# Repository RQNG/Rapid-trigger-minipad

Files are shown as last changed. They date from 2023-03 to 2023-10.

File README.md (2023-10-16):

# Rapid-trigger-minipad
Rapid trigger是Wooting键盘的特色功能，是指没有固定键程，靠上下移动判定触发的功能，能解决切指卡手的大难题，传言能破解osu!这款游戏。

我本来想尝试一下wooting，但其价格昂贵，没有渠道，二手抢钱等等问题让我很不爽，于是决定自己做，我想这也是许多玩家想做的，所以我将它分享出来，现在，它属于每一名玩家了。

本项目提供三种主控方案，其中以STM32为主，出于性能和性价比考虑，CH552和RP2040版本将不再更新，但仍然保留代码给有需要的人。

按键为独立模块并且全部使用杜邦线连接，按键间距可调，STM32版本最多支持10个模拟输入按键，这应该能满足大部分玩家在按键数量和个性化上的需求了。

这并不是很厉害的技术，但确实还算有趣，感兴趣的话欢迎尝试制作。我希望这个项目越多人关注越好，最好在玩家群体里流行开来，我认为这种功能被说是走捷径的根源就是不够普及，所以都来用吧。

参考或使用此项目请遵守附带的开源协议，如愿意分享，欢迎投稿至第三方文件夹。



# 项目特点
* 制作简单，无需任何专业操作（如焊接等）和专业知识就能制作。
* 无法垄断，所有材料在国内都有渠道购买并且供货充足。
* 本地控制，增加控制器，除按键总键程外，所有设置都可以在本地完成。
* 丝滑菜单，控制器使用模仿稚晖君MonoUI的多级菜单，动画被优化到非常丝滑，可以当解压玩具（真的）。
* 按键数多，最多能添加10个模拟按键，多于市面上其它方案，并且每个按键都可以不一样。
* 三种模式，支持不同极性按键，不同极性传感器的所有组合，组合对应两个模式，还有禁用模式。
* 键距可调，每个按键为独立制作并且可以在外壳内自由摆放，提供多种宽度的填充模块。
* 成本较低，使用stm32作为主控，价格比arduino更低，按键数量可以自行选择以降低成本。
* 性能更好，经测试，ADC精度比频率等因素更影响表现，而stm32有精度更高的ADC，因此是最优选择。

# 控制器
主菜单：

屏幕截图 2023-05-29 011856

编辑页：

屏幕截图 2023-05-29 012131

弹窗：

屏幕截图 2023-05-29 012300

电压测量页：

屏幕截图 2023-05-29 012449

演示视频：https://www.bilibili.com/video/BV17T41187xi/

控制器使用0.96寸OLED显示，EC11旋钮控制，使用了我的另一个项目：WouoUI，关于UI的描述请查看该项目。

控制器支持调整的参数：
* 触发值
* 释放值
* 上死区
* 下死区
* 键值
* 模式（压缩包内的代码不支持该项）
* 初始化时放大抖动的倍数

注意：
* 外壳模型尚未支持安装屏幕和旋钮，请自行修改外壳，否则请使用压缩包内的代码。
* 安装轴体下的磁铁时，请使用压缩包内的工具代码，检查磁铁方向是否安装正确，要求按下增大，释放减小。
* 控制器是给以后可能使用的成品轴体设计的，轴体极性不确定，手制轴体的话，可以确保表现的唯一，无需另一种模式。
* 压缩包内的代码，Rapid trigger功能部分，与更高版本没有本质区别，无需介意版本号较低。

# 内部结构
四按键版本：

Notes_230225_033130_2

十按键版本：

Notes_230225_033130_2 (1)

# 制作教程
1. 轴体改造篇：https://www.bilibili.com/read/cv21948435
2. 软件设置篇：https://www.bilibili.com/read/cv21969155
3. 硬件组装篇：https://www.bilibili.com/read/cv21985212

# 参考项目
1. hall-2k-keypad-handmade：https://github.com/chent7/hall-2k-keypad-handmade（主要）
2. 如何DIY一款属于自己的HID键盘：https://mp.weixin.qq.com/s/o-8_3SQS2AGT_WTyTLYQnA
3. 【三键侧透光小键盘】CH552G：https://oshwhub.com/phantomr/styudy-xiao-jian-pan-ch552g

# 推荐项目
下列项目都有Rapid trigger功能，它们各有优势，对我的项目有建议的，在给出建议之外，也可以尝试在这些项目中寻找解决方案。

* hall-2k-keypad-handmade: https://github.com/chent7/hall-2k-keypad-handmade
* cap4k：https://github.com/MaticsL/cap4k
* minipad-firmware-old: https://github.com/minipadKB/minipad-firmware-old
* minipad-firmware: https://github.com/minipadKB/minipad-firmware
* fluxpad: https://github.com/sssata/fluxpad
* the-poor-mans-keypad-and-future-wooting: https://www.reddit.com/r/osugame/comments/zpcvkw/the_poor_mans_keypad_and_future_wooting/
* making-a-diy-wooting-keypad: https://www.reddit.com/r/osugame/comments/117v6xd/making_a_diy_wooting_keypad/
* DIY under 20$ WOOTING like Keypad for Osu! (analog switches): https://www.youtube.com/watch?v=4rrDy9KakRI&t=10s&ab_channel=prAlex
* BexPad: https://github.com/Bexin3/BexPad

# 改进空间
目前我的方案在通用性和表现上都已经很不错了，动手能力不强的普通玩家完全可以放心尝试，不会令你们失望的。
对于不惜代价追求极致的人来说，我的方案可能显得太过廉价，因此在这里提出一些改进空间，欢迎尝试，如果愿意分享的话，请合并在第三方设计项目中供他人参考。

* 使用stm32作为主控，不是因为廉价，而是因为它拥有最高的ADC分辨率，这个最影响体验。
* 使用stm32标准库或者hal库实现通信功能，因为有成熟的方案可用，但因为IDE劝退新手而弃用。
* 使用AH491线性霍尔传感器，这种灵敏度很高为15mv/Gs，但相对的会放大抖动，因为不好调试而弃用。
* 使用pcb，能降低干扰并且有助于批量化生产，但因为无法实现可调键距和需要焊接而弃用。
* 使用成品磁轴，轴芯有个小磁铁跟着上下移动的那种，因为有垄断风险而弃用，目前已知的有三种：
  1. wooting的lekker轴，这个要海淘。
  2. 佳达隆的ks-20，这个买不到。
  3. 东莞市益谦电子有限公司，1688搜索“磁轴”能找到，应该能买到。

# 建议收集
可以直接在GitHub上提建议，也可以在B站专门的动态下提。

* 初版方案建议收集动态：https://t.bilibili.com/757193959862697993

# 赛博乞讨（划掉
开发不易，如果有帮到你，请我喝杯咖啡可好


# 更新
## 软件

### v 3.2
* 优化动画函数，动画结束后不会再进行无意义的浮点数计算。

### v 3.1
* 修复EC11旋钮使界面卡死的问题，感谢 GitHub 安红豆 提供的线索。

### v 3.0
* UI 流畅度优化，实现了优雅的平滑动画，动画算法被优化到只有两行。
* UI 架构优化，基本重构了 v2.x，实现了独立弹窗，白天和黑暗模式，单选和多选框，开关等。
* 删除主界面列表菜单风格，增加主界面图标动画可选项。
* 删除关于本机页配置查看功能，增加参数修改页面，参数直接显示在每行末尾功能。
* 选择框跳转动画改为宽度和竖直方向位置都从当前位置到上一级选中位置平滑过渡。
* 增加动画速度可调区间。10 ~ 100。
* 修复循环模式选择框在跳转动画未结束前，选择项后退时，列表与屏幕错位的问题。
* 修复选择框在选择滚动过快时，滚出屏幕外的问题。
* 增加独立弹窗动画，背景虚化开关功能。
* 重新设计电压测试页，增加波形显示功能，现在可以同时观察数值和波形。

### v 2.1
* 重构代码，只保存路径和选择框所在位置，分页面类型定义变量。
* 增加图标和列表两种主界面风格。
* 支持本地查看所有配置，在关于本机页面。
* 支持128×64，128×32两种主流OLED屏幕分辨率，只需要替换驱动即可。
* 增加列表展开动画效果。
* 增加选择框展开和跳转动画效果。
* 增强动画速度的可调精度。
* 增加循环模式。
* 增加旋钮方向反转选项。

### v 2.0
* 增加模仿MonoUI的丝滑菜单。
* 支持不同极性的轴和不同极性的传感器，使用对应模式即可。
* 支持在本地设置所有参数。
* 支持断电保存功能。
* 支持引脚测试，可以在本地查看引脚电压变化曲线。

### v 1.3
* 初始化改为并行扫描，按键数增加不会明显延长初始化时间。
* 增加初始化指示灯，在板子上的蓝灯未熄灭前，不要按下按键。

### v 1.2 
* 解决了插入后微小干扰下误触发的bug。
* 增加了上下死区。
* 增加除字母外其它按键的支持。

### v 1.1 
* 解决了插入后不断输入的bug。
* 优化了初始化方式。

### v 1.0 
* 简单移植hall-2k-keypad-handmade。

## 硬件：

### v 1.2
* 增加OLED显示屏。
* 增加EC11旋钮。

### v 1.1 
* 增加十按键版本外壳模型。
* 增加几种填充模块模型。

### v 1.0 
* 四按键版本外壳模型。
* 独立按键所需模型。
* 材料清单。

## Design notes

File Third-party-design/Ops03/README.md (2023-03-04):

# 未经验证，谨慎使用

# Ops03 by OctopusZ
Ops03 是一个基于ch552t，使用了三个磁轴的键盘项目

# without verification，Use with caution

# Ops03 by OctopusZ
Ops03 is a keyboard project based on ch552t and using three magnetic swtich.

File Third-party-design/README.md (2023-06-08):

# 第三方项目
基于Rapid-trigger-minipad展开的第三方项目

# 目录
* Ops03：基于ch552t，使用了三个磁轴的键盘项目，作者：OctopusZ
* wheatPad：作者：wheatEars

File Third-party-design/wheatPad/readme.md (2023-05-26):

# 注意

方案未经验证，谨慎使用

新增两个微动，修改ui程序可以用来按esc和重开~

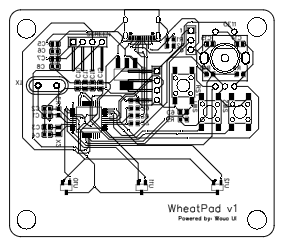
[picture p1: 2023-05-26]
Third-party-design/wheatPad/PCB.png

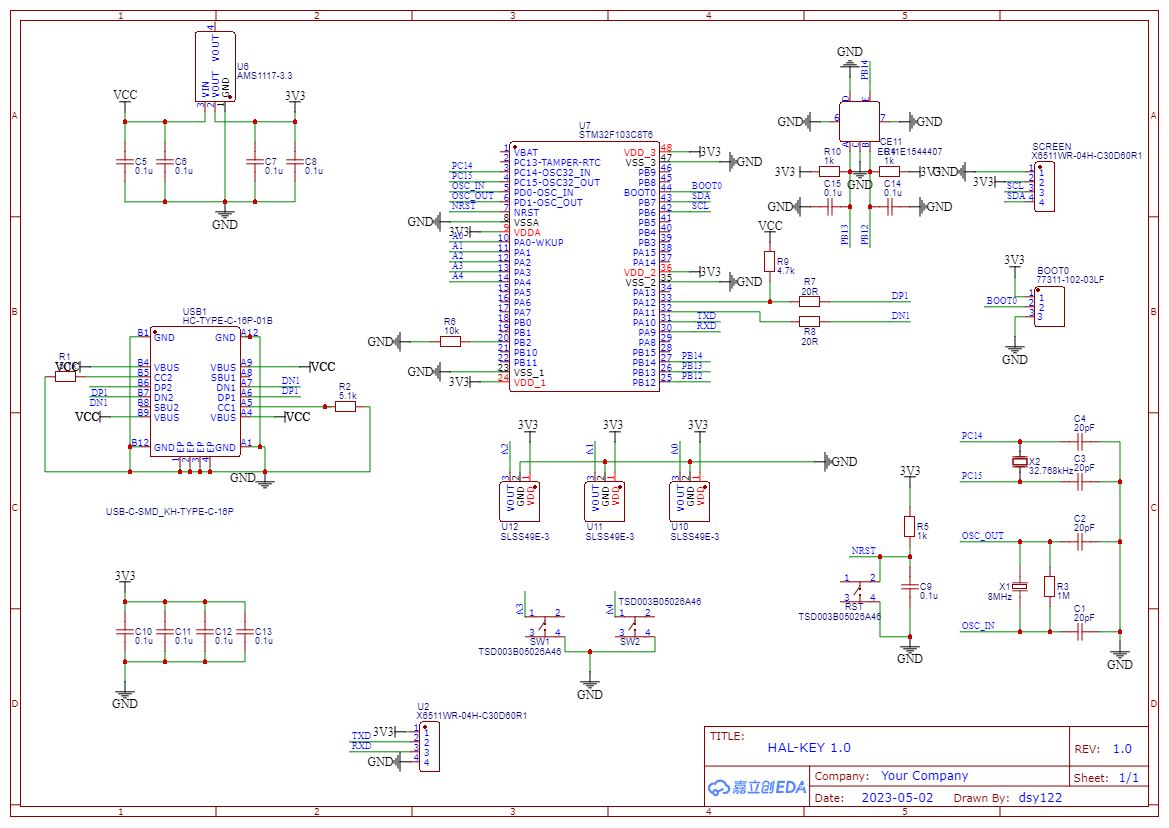
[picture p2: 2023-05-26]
Third-party-design/wheatPad/原理图.png

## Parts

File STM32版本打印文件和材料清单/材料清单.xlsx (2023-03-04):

工具 | 数量 | 价格 | 店铺 | 备注 | 可用的线性霍尔传感器
锉刀，镀镍3mm×5件套 | 1件 | 9.5 | greener绿林旗舰店 |  | SS49E | 1.8 - 2.0 mv/G
刻刀 | 1把 | ？ | 楼下小卖部 |  | MH49E | 1.8 - 2.0 mv/G
502胶水（晨光，粘稠状） | 1管 | ？ | 楼下小卖部 |  | AH602 | 2.5 mv/G
拆轴器 | 1个 | ？ | 未知 | 我是用牙线尾端撬开的 | AH603 | 3.25 mv/G
斜嘴钳 | 1把 | ？ | 本来就有 |  | AH605 | 5 mv/G
尖嘴钳 | 1把 | ？ | 本来就有 |  | CH603 | 3.3 mv/G
尺子 | 1把 | ？ | 本来就有 |  | CH604 | 2.5 mv/G
 |  |  |  |  | CH605 | 5 mv/G
 |  |  |  |  | AH491 | 15 mv/G
 |  |  |  |  | AH492 | 7.5 mv/G
 |  |  |  |  | AH493 | 3.7 mv/G
材料 | 数量 | 价格 | 店铺 | 备注 | AH494 | 2 mv/G
杜邦线，10cm，公对公 | 1排 | 3.44 | risym旗舰店
杜邦线，10cm，公对母 | 1排 | 3.56 | risym旗舰店
杜邦线，21cm，母对母 | 1排 | 2.38 | risym旗舰店 | 十按键版本不知道怎么买，自己估计一下
圆柱形磁铁，直径2mm，厚3mm | 50个 | 6.5 | 博讯微数码专营店
TTC新版金粉轴V2 | 4个 | 12.8 | 深圳市金盛达电子 | 建议多买几个练手
STM32F103C8T6单片机，排针向下焊接 | 1个 | 17.1 | 无名科技Nologo
线性霍尔传感器 | 4个 | 10 | 深圳信芯电子商行 | 多种型号可以用，详情看右边的列表，捡有货的最灵敏的买即可，体感差别不大，选直插型号的
H62黄铜管，外径2mm，内径1.6mm，0.5m | 1根 | 10 | 上海金属材料经营部
面包板，长8.5cm，宽5.5cm | 1个 | 2.8 | 深圳市优信电子科技有限公司
USB转TTL模块 | 1个 | 4.5 | 深圳市优信电子科技有限公司
3D打印 | 1次 | 90 | 卓越三维产品设计打印服务 | 不要用三维猴打印，精度不够

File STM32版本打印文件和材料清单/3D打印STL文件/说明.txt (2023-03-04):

文件夹名称表示的数量为该外壳最多能容纳的按键数量，不代表真的要做那么多按键。

如果不需要那么多按键，请选择填充模块进行填充，填充模块可以用于调节按键间距。

请先确定好所需按键数和摆放方式，选择合适的外壳模型和填充模块，确定好数量。

注意，十按键版触盘外壳未经过实际测试，如果有任何问题请在建议动态中留言，

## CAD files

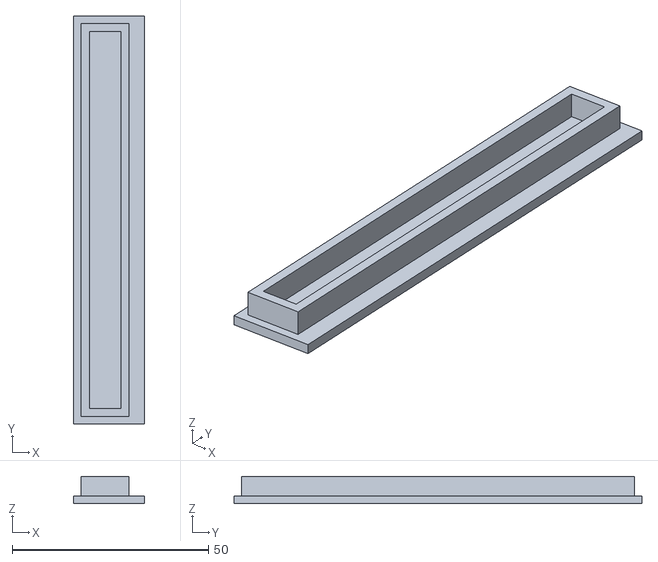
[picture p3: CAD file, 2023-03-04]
STM32版本打印文件和材料清单/3D打印STL文件/十按键版触盘外壳打印件/4. 触盘外壳D，2件.stl
18.0 x 104.0 x 7.00

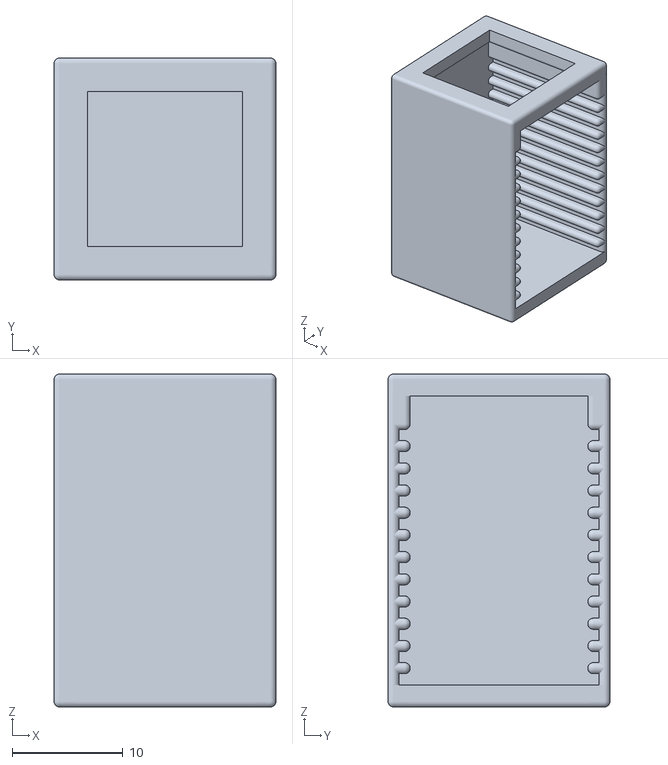
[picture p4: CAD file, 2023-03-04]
STM32版本打印文件和材料清单/3D打印STL文件/单个按键打印件/4. 按键外壳，1件.stl
20.0 x 20.0 x 30.0

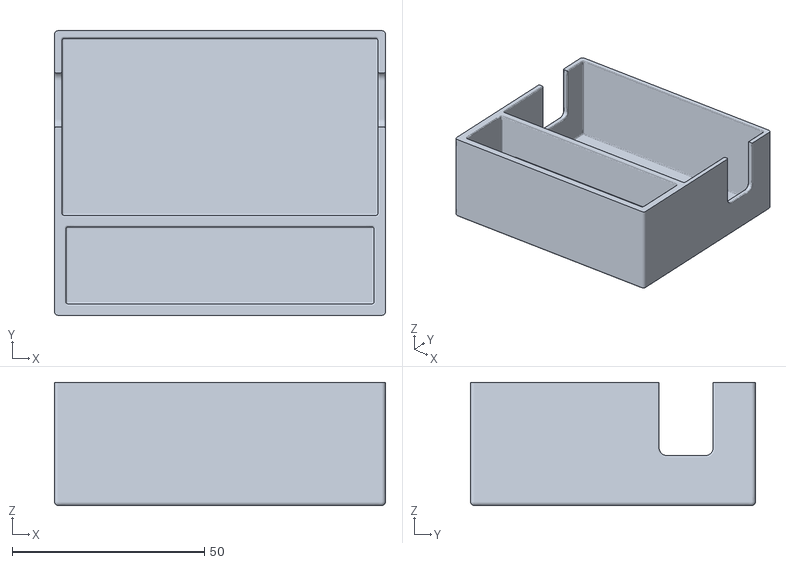
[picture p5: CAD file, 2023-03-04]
STM32版本打印文件和材料清单/3D打印STL文件/四按键版触盘外壳打印件/1. 触盘外壳A，1件.stl
86.0 x 74.0 x 32.0

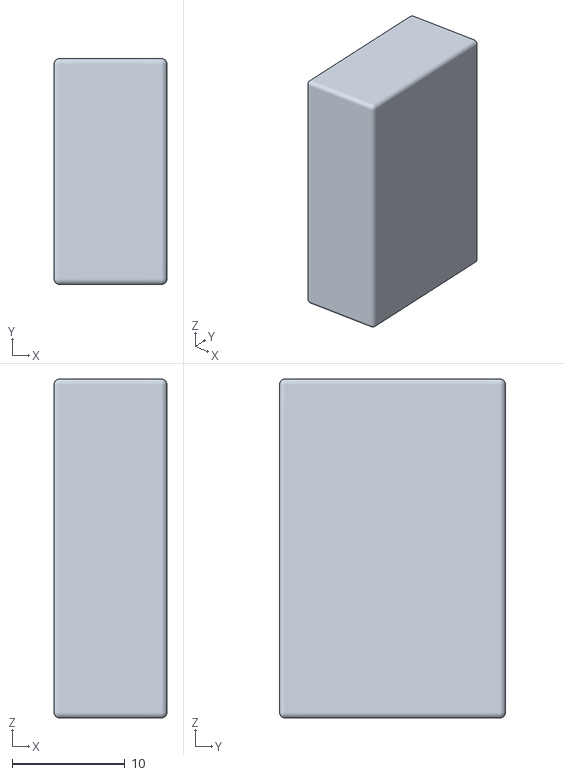
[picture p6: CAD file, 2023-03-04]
STM32版本打印文件和材料清单/3D打印STL文件/填充模块打印件/一个按键长，半个按键宽的填充块.stl
10.0 x 20.0 x 30.0

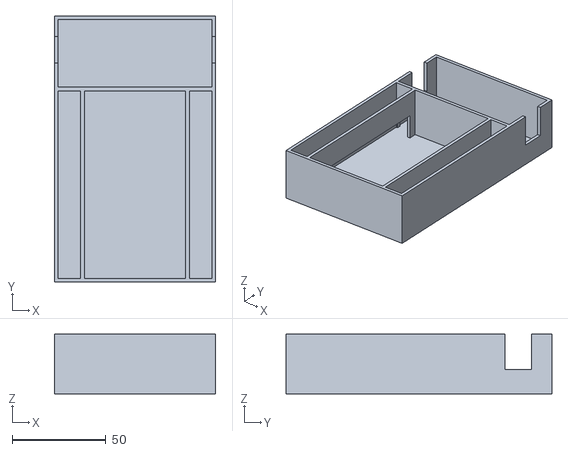
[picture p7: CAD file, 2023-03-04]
STM32版本打印文件和材料清单/3D打印STL文件/十按键版触盘外壳打印件/1. 触盘外壳A，1件.stl
86.0 x 142.0 x 32.0

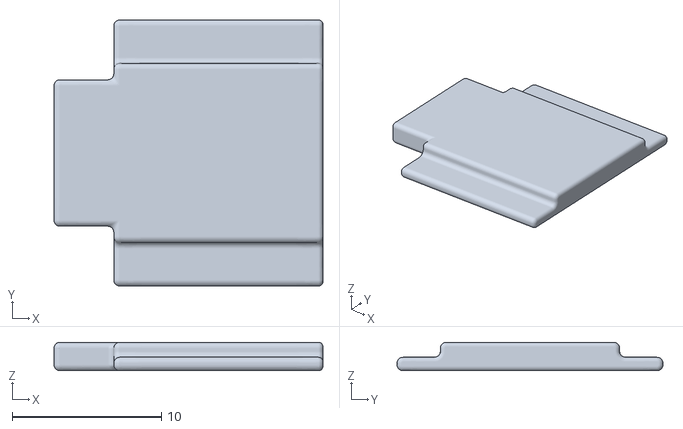
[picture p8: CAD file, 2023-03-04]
STM32版本打印文件和材料清单/3D打印STL文件/单个按键打印件/3 .探头固定器B，1件.stl
18.0 x 17.8 x 1.90

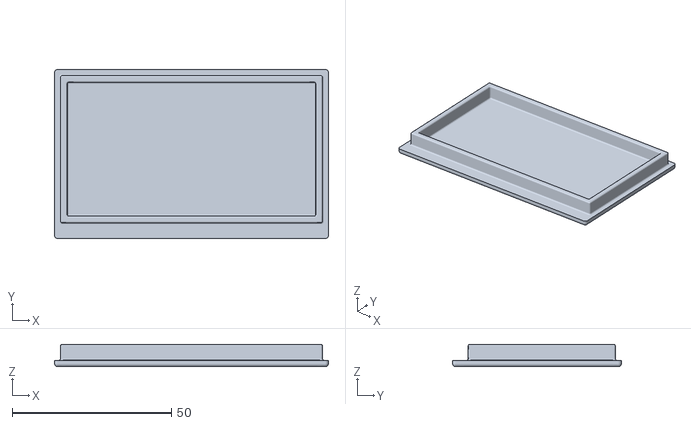
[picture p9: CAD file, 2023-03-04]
STM32版本打印文件和材料清单/3D打印STL文件/四按键版触盘外壳打印件/2. 触盘外壳B，1件.stl
86.0 x 53.0 x 7.00

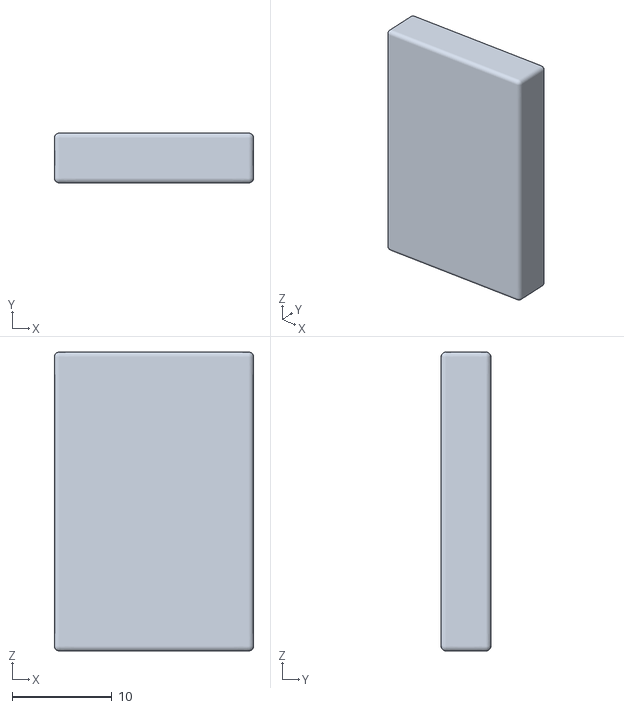
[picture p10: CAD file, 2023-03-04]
STM32版本打印文件和材料清单/3D打印STL文件/填充模块打印件/一个按键长，四分之一个按键宽的填充块.stl
20.0 x 5.00 x 30.0

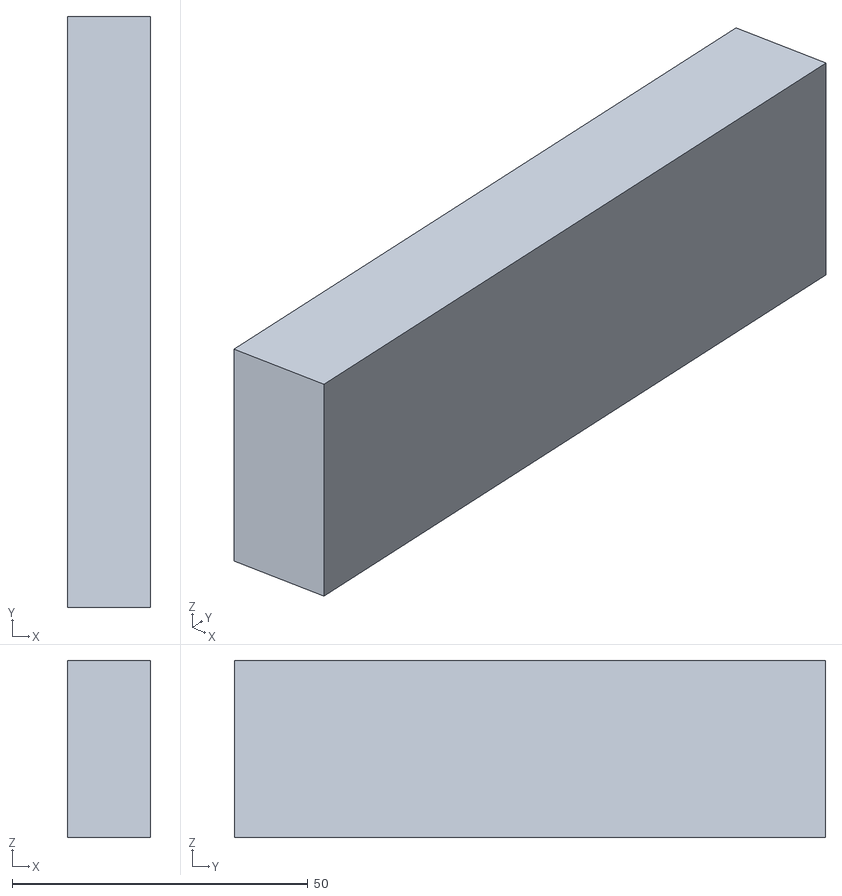
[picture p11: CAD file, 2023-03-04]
STM32版本打印文件和材料清单/3D打印STL文件/十按键版触盘外壳打印件/3. 触盘外壳C，1件.stl
14.0 x 100.0 x 30.0

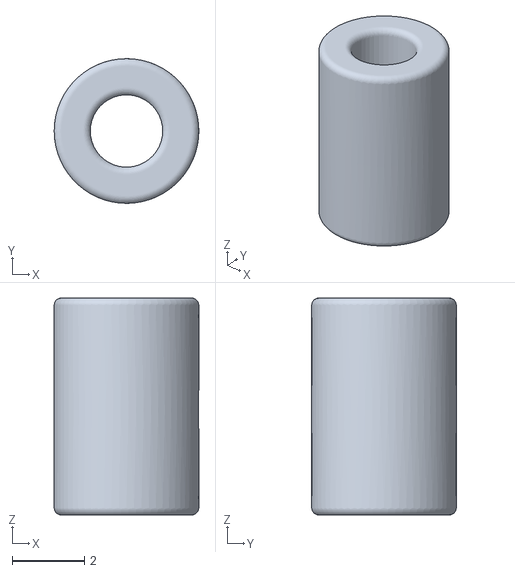
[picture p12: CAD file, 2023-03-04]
STM32版本打印文件和材料清单/3D打印STL文件/单个按键打印件/1. 磁铁固定器，1件.stl
4.00 x 4.00 x 6.00

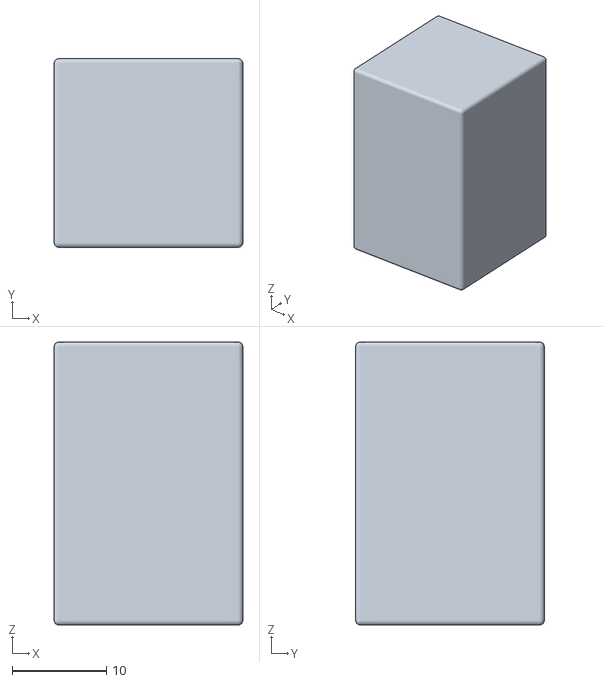
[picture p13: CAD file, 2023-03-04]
STM32版本打印文件和材料清单/3D打印STL文件/填充模块打印件/一个按键长，一个按键宽的填充块.stl
20.0 x 20.0 x 30.0

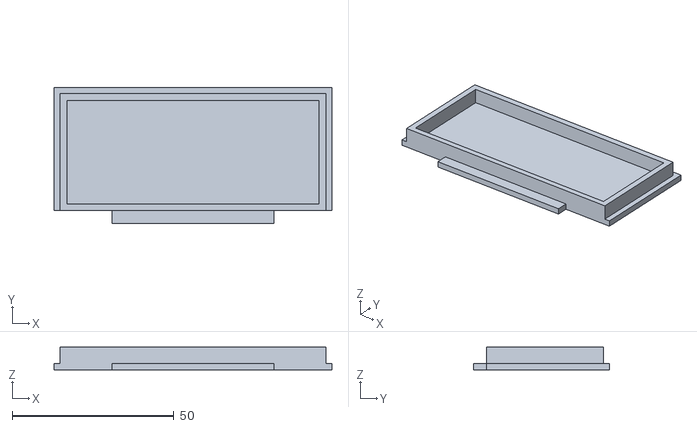
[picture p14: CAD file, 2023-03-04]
STM32版本打印文件和材料清单/3D打印STL文件/十按键版触盘外壳打印件/2. 触盘外壳B，1件.stl
86.0 x 42.0 x 7.00

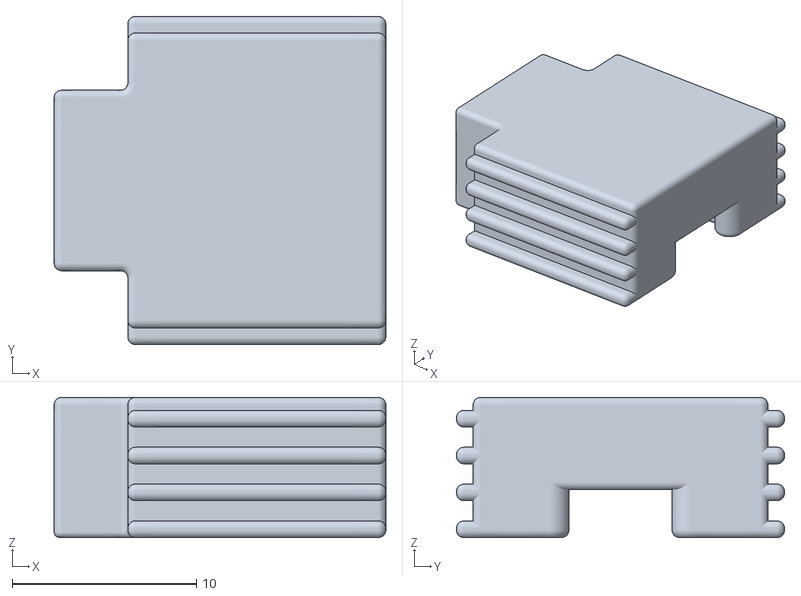
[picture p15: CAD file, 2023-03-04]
STM32版本打印文件和材料清单/3D打印STL文件/单个按键打印件/2. 探头固定器A，1件.stl
18.0 x 17.8 x 7.60

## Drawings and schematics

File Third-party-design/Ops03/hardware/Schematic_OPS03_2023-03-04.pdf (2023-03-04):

## USB接口

GND B1A12 VBUS A9B4 CC1 A5 DP1 A6 DN1 A7 SBU1 A8 CC2 B5 DP2 B6 DN2 B7 SBU2 B8 VBUS A9B4 GND B1A12 SHELL 0

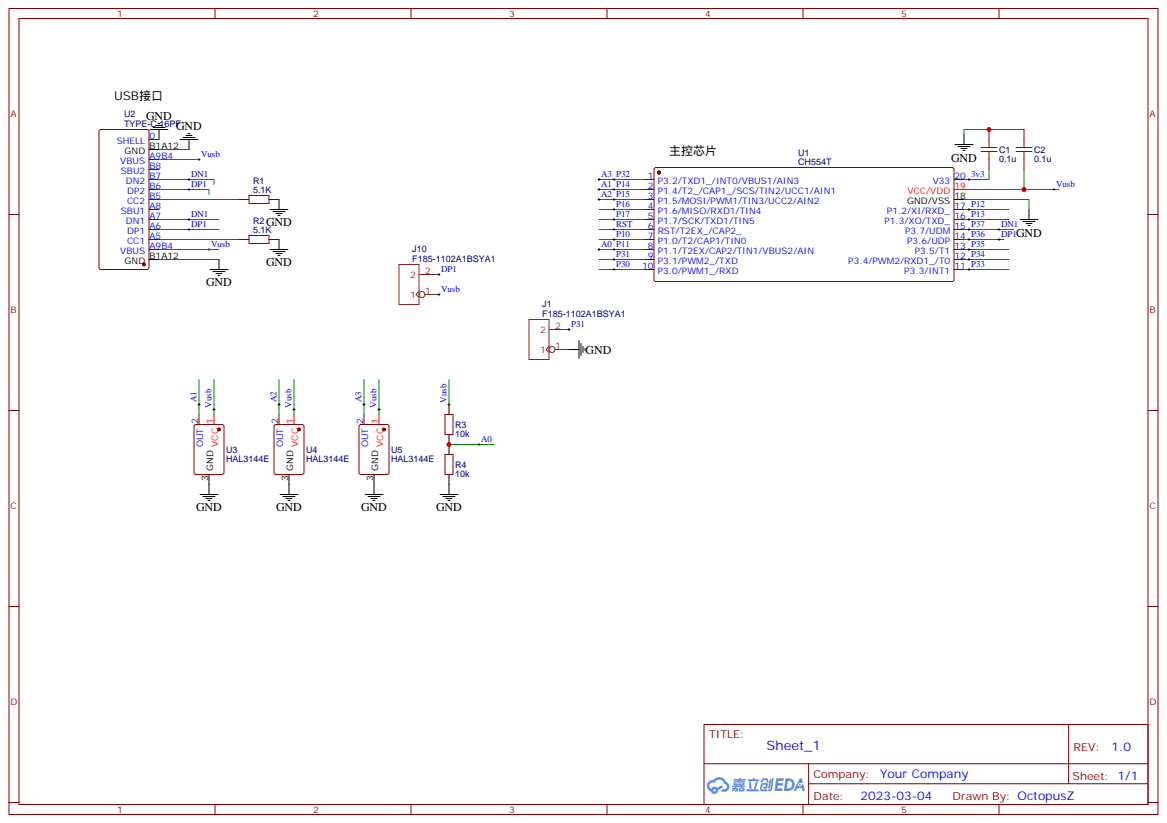
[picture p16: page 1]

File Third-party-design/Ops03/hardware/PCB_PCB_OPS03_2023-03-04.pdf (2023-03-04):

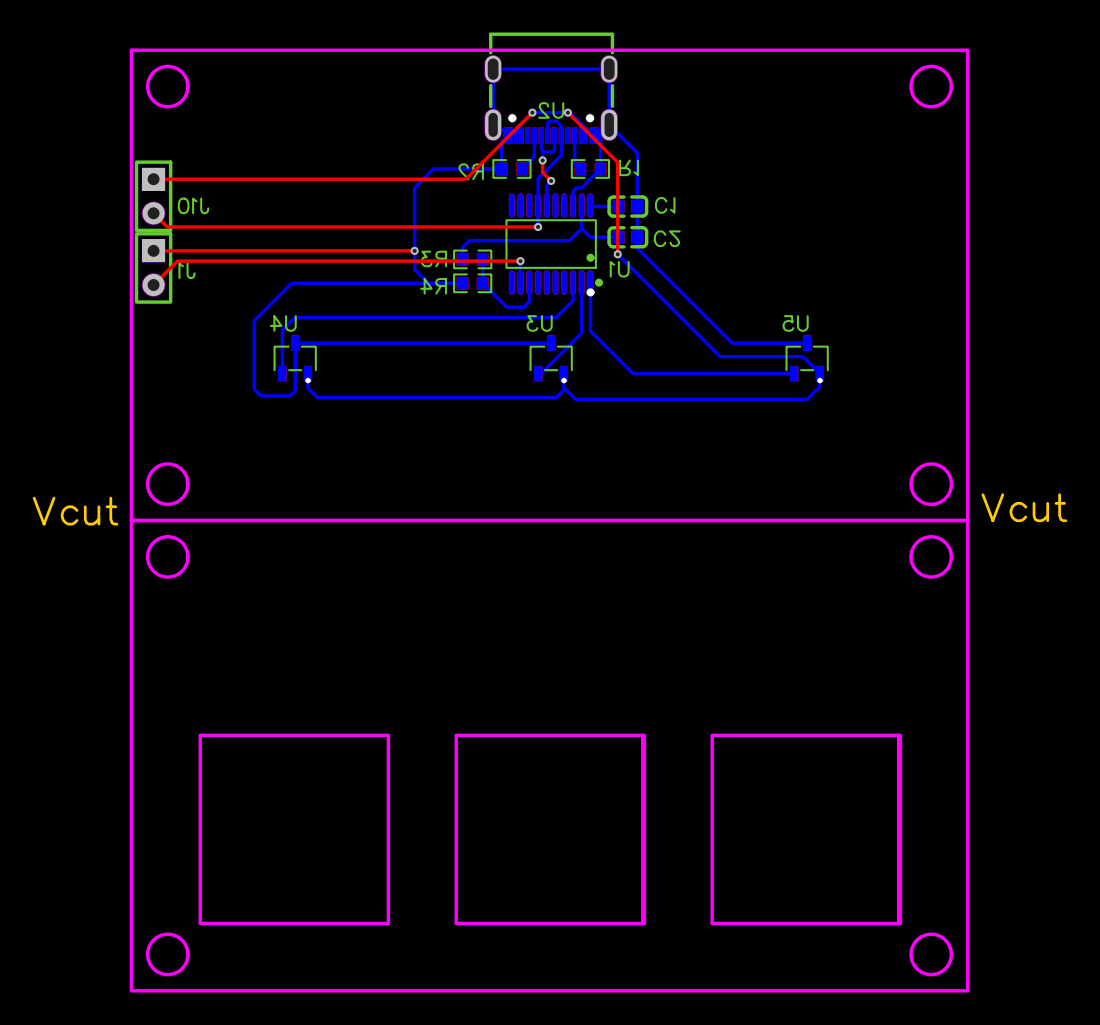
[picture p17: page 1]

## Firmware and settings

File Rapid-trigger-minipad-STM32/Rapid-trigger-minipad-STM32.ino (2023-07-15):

/*
  此程序用于实现 wooting 键盘中的 Rapid trigger 功能。
  
  主功能移植并优化自 Github 上的一个开源项目，添加了按键的独立参数和两端的死区，优化了初始化方式，增加控制器，模仿稚晖君 MonoUI 的超丝滑菜单。

  v3.2 更新内容：

    * 优化动画函数，动画结束后不会再进行无意义的浮点数计算
    
  v3 功能：

    * 此程序可视为 WouoUI v2.0 例程，WouoUI 是从此程序 v2.x 版本衍生出的 UI 架构。
    * UI 流畅度优化，实现了优雅的平滑动画，动画算法被优化到只有两行。
    * UI 架构优化，基本重构了 v2.x，实现了独立弹窗，白天和黑暗模式，单选和多选框，开关等功能。
    * 删除主界面列表菜单风格，增加主界面图标动画可选项，回到主界面时，图标可以从正上方当前位置向两边发牌，或者从左上方从头开始发牌。
    * 删除关于本机页配置查看功能，增加参数修改页面，参数直接显示在每行末尾功能。
    * 选择框跳转动画改为宽度和竖直方向位置都从当前位置到上一级选中位置平滑过渡。
    * 增加动画速度可调区间。10 ~ 100。
    * 修复循环模式选择框在跳转动画未结束前，选择项后退时，列表与屏幕错位的问题。
    * 修复选择框在选择滚动过快时，滚出屏幕外的问题（虽然我觉得这是个有趣的特性，只要往回滚动就好不影响正常使用）。
    * 增加独立弹窗动画，背景虚化开关功能（开启虚化会有轻微卡顿感，但或许有些人喜欢，因此保留可选项）。
    * 重新设计电压测试页，增加波形显示功能，现在可以同时观察数值和波形。
  
  测试用开发板为STM32 F103C8T6，以下是使用说明：

    硬件：

    * EC11：A -> PB13 ; B -> PB12 ; S -> PB14 ; 电源3.3v
    * OLED：四线，0.96 SSD1306 128*64，SDA -> PB7 ; SCL -> PB6 ; 电源3.3v
    * 板子上的跳线帽设置：BOOT0 -> 1 ; BOOT1 -> 0 
    * 串口模块与板子连线：GND -> GND ; 3V3 -> 3.3V ; RX -> PA9 ; TX -> PA10，其余引脚空着。
    * 串口与电脑连接，用数据线连接板子上的母口和电脑。
    * 点击IDE左上角向右箭头的按钮，等待编译和上传完成。
    * 上传完成后如要测试手感，无需断开串口模块，但需要拔插数据线，电脑才能识别到是USB设备。
    * 当BOOT在第一条所述设置时，上传完成后，第一次拔插数据线时电脑会认到USB设备，从第二次开始就认不到了。
    * 手感调试合适后修改跳线帽的设置为：BOOT0 -> 0 ; BOOT1 -> 0。设置后就能收起串口模块了。
  
    软件：
    
    * 文件 -> 首选项 -> 其他开发板管理器地址 -> 添加一行：http://dan.drown.org/stm32duino/package_STM32duino_index.json
    * 工具 -> 开发板 -> 开发板管理器 -> 搜索stm32F1，下载STM32F1xx开头的库
    * 工具 -> 开发板 -> stm32F1... -> Generic STM32F103C series
    * 工具 -> 端口：“COMX” -> COMX（X为设备对应端口号）
    * 工具 -> Upload method -> Serial
    * 进入目录C:\Users{username}\AppData\Local\Arduino15\packages\stm32duino\hardware\STM32F1{版本名称}\libraries\USBComposite下，打开usb_hid.c文件，搜索bInterval，将该值修改为0x01，即轮询间隔修改为1ms
    
    注意：

    * 上传程序前，先确认使用的轴的总键程是否为4mm，如果不是，需要修改 key 数组变量中代表 travel 一列的相关参数，单位0.1mm，即4mm的值为40。
    * 拔插USB后，正常情况下，屏幕会变黑，板子上的蓝灯会点亮一秒钟，点亮时不要动按键，这是在初始化。
    * 初始化后，每个按键都需要按下一次后才能正常使用，按下时要按到底。

  遇到困难的话参考以下资料：

    设置参考：
    
    * https://github.com/rogerclarkmelbourne/Arduino_STM32
    * https://baijiahao.baidu.com/s?id=1727012582049990775&wfr=spider&for=pc
    * https://blog.csdn.net/oChiTu1/article/details/108166233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
    
    项目参考：
    
    * Rapid trigger功能：https://github.com/chent7/hall-2k-keypad-handmade
    * STM32触盘：https://mp.weixin.qq.com/s/o-8_3SQS2AGT_WTyTLYQnA
    * UI：https://www.bilibili.com/video/BV1HA411S7pv/ ; https://www.bilibili.com/video/BV1xd4y1C7BE/
    
  本项目使用Apache 2.0开源协议，如需商用或借鉴，请阅读此协议。
  
  欢迎关注我的B站账号，一个只分享osu!相关内容，很无聊的帐号。
  
  用户名：音游玩的人，B站主页：https://space.bilibili.com/9182439?spm_id_from=..0.0
*/

/************************************* 屏幕驱动 *************************************/

//分辨率128*64，可以使用硬件IIC接口

#include <U8g2lib.h>
#include <Wire.h>

#define   SCL   PB6
#define   SDA   PB7
#define   RST   U8X8_PIN_NONE

U8G2_SSD1306_128X64_NONAME_F_HW_I2C u8g2(U8G2_R0, SCL, SDA, RST);     // 分辨率：128*64  驱动：SSD1306  接口：IIC（硬件）

/************************************* 定义页面 *************************************/

//总目录，缩进表示页面层级
enum 
{
  M_WINDOW,
  M_SLEEP,
    M_MAIN, 
      M_EDITOR,
        M_KNOB,
          M_KRF,
        M_KEYS,
          M_KCODE,
          M_KMODE,
      M_VOLT,
      M_SETTING,
        M_ABOUT,
};

//状态，初始化标签
enum
{
  S_FADE,       //转场动画
  S_WINDOW,     //弹窗初始化
  S_LAYER_IN,   //层级初始化
  S_LAYER_OUT,  //层级初始化
  S_NONE,       //直接选择页面
};

//菜单结构体
typedef struct MENU
{
  char *m_select;
} M_SELECT;

/************************************* 定义内容 *************************************/

/************************************* 文字内容 *************************************/

M_SELECT main_menu[]
{
  {"Sleep"},
  {"Editor"},
  {"Volt"},
  {"Setting"},
};

M_SELECT editor_menu[]
{
  {"[ Editor ]"},
  {"- Knob"},
  {"- Key 0"},
  {"- Key 1"},
  {"- Key 2"},
  {"- Key 3"},
  {"- Key 4"},
  {"- Key 5"},
  {"- Key 6"},
  {"- Key 7"},
  {"- Key 8"},
  {"- Key 9"},
};

M_SELECT knob_menu[]
{
  {"[ Knob ]"},
  {"# Rotate Func"},
  {"$ Press Func"},
};

M_SELECT krf_menu[]
{
  {"[ Rotate Function ]"},
  {"--------------------------"},
  {"= Disable"},
  {"--------------------------"},
  {"= Volume"},
  {"= Brightness"},
  {"--------------------------"},
};

M_SELECT keys_menu[]
{
  {"[ Keys ]"},
  {"~ Trigger"},
  {"~ Release"},
  {"~ Top"},
  {"~ Bottom"},
  {"~ Times"},
  {"$ Codes"},
  {"& Modes"},
};

M_SELECT kcode_menu[]
{
  {"[ Key Code ]"},
  {"--------------------------"},
  {"= Disable"},
  {"--------------------------"},
  {"= A"},
  {"= B"},
  {"= C"},
  {"= D"},
  {"= E"},
  {"= F"},
  {"= G"},
  {"= H"},
  {"= I"},
  {"= J"},
  {"= K"},
  {"= L"},
  {"= M"},
  {"= N"},
  {"= O"},
  {"= P"},
  {"= Q"},
  {"= R"},
  {"= S"},
  {"= T"},
  {"= U"},
  {"= V"},
  {"= W"},
  {"= X"},
  {"= Y"},
  {"= Z"},
  {"--------------------------"},
  {"= 0"},
  {"= 1"},
  {"= 2"},
  {"= 3"},
  {"= 4"},
  {"= 5"},
  {"= 6"},
  {"= 7"},
  {"= 8"},
  {"= 9"},
  {"--------------------------"},
  {"= Esc"},
  {"= F1"},
  {"= F2"},
  {"= F3"},
  {"= F4"},
  {"= F5"},
  {"= F6"},
  {"= F7"},
  {"= F8"},
  {"= F9"},
  {"= F10"},
  {"= F11"},
  {"= F12"},
  {"--------------------------"},
  {"= Left Ctrl"},
  {"= Left Shift"},
  {"= Left Alt"},
  {"= Left Win"},
  {"= Right Ctrl"},
  {"= Right Shift"},
  {"= Right Alt"},
  {"= Right Win"},
  {"--------------------------"},
  {"= Caps Lock"},
  {"= Backspace"},
  {"= Return"},
  {"= Insert"},
  {"= Delete"},
  {"= Tab"},
  {"--------------------------"},
  {"= Home"},
  {"= End"},
  {"= Page Up"},
  {"= Page Down"},
  {"--------------------------"},
  {"= Up Arrow"},
  {"= Down Arrow"},
  {"= Left Arrow"},
  {"= Right Arrow"},
  {"--------------------------"},
};

M_SELECT kmode_menu[]
{
  {"[ Mode ]"},
  {"--------------------------"},
  {"= Mode 1"},
  {"= Mode 2"},
  {"--------------------------"},
};

M_SELECT volt_menu[]
{
  {"A0"},
  {"A1"},
  {"A2"},
  {"A3"},
  {"A4"},
  {"A5"},
  {"A6"},
  {"A7"},
  {"B0"},
  {"B1"},
};

M_SELECT setting_menu[]
{
  {"[ Setting ]"},
  {"~ Disp Bri"},
  {"~ Tile Ani"},
  {"~ List Ani"},
  {"~ Win Ani"},
  {"~ Spot Ani"},
  {"~ Tag Ani"},
  {"~ Fade Ani"},
  {"~ Btn SPT"},
  {"~ Btn LPT"},
  {"+ T Ufd Fm Scr"},
  {"+ L Ufd Fm Scr"},
  {"+ T Loop Mode"},
  {"+ L Loop Mode"},
  {"+ Win Bokeh Bg"},
  {"+ Knob Rot Dir"},
  {"+ Dark Mode"},
  {"- [ About ]"},
};

M_SELECT about_menu[]
{
  {"[ WouoUI ]"},
  {"- Version: v2.2"},
  {"- Board: STM32F103"},
  {"- Ram: 20k"},
  {"- Flash: 64k"},
  {"- Freq: 72Mhz"},
  {"- Creator: RQNG"},
  {"- Billi UID: 9182439"},  
};

/************************************* 图片内容 *************************************/

PROGMEM const uint8_t main_icon_pic[][120]
{
  {
    0xFF,0xFF,0xFF,0x3F,0xFF,0xFF,0xFF,0x3F,0xFF,0xFF,0xFF,0x3F,0xFF,0xFF,0xF1,0x3F,
    0xFF,0xFF,0xC3,0x3F,0xFF,0xFF,0x87,0x3F,0xFF,0xFF,0x07,0x3F,0xFF,0xFF,0x0F,0x3E,
    0xFF,0xFF,0x0F,0x3E,0xFF,0xFF,0x0F,0x3C,0xFF,0xFF,0x0F,0x3C,0xFF,0xFF,0x0F,0x38,
    0xFF,0xFF,0x0F,0x38,0xFF,0xFF,0x0F,0x38,0xFF,0xFF,0x07,0x38,0xFF,0xFF,0x07,0x38,
    0xFF,0xFF,0x03,0x38,0xF7,0xFF,0x01,0x38,0xE7,0xFF,0x00,0x3C,0x87,0x3F,0x00,0x3C,
    0x0F,0x00,0x00,0x3E,0x0F,0x00,0x00,0x3E,0x1F,0x00,0x00,0x3F,0x3F,0x00,0x80,0x3F,
    0x7F,0x00,0xC0,0x3F,0xFF,0x01,0xF0,0x3F,0xFF,0x07,0xFC,0x3F,0xFF,0xFF,0xFF,0x3F,
    0xFF,0xFF,0xFF,0x3F,0xFF,0xFF,0xFF,0x3F
  },
  {
    0xFF,0xFF,0xFF,0x3F,0xFF,0xFF,0xFF,0x3F,0xFF,0xFF,0xFF,0x3F,0xFF,0xF9,0xE7,0x3F,
    0xFF,0xF9,0xE7,0x3F,0xFF,0xF9,0xE7,0x3F,0xFF,0xF0,0xE7,0x3F,0x7F,0xE0,0xE7,0x3F,
    0x7F,0xE0,0xC3,0x3F,0x7F,0xE0,0xC3,0x3F,0x7F,0xE0,0xC3,0x3F,0x7F,0xE0,0xE7,0x3F,
    0xFF,0xF0,0xE7,0x3F,0xFF,0xF9,0xE7,0x3F,0xFF,0xF9,0xE7,0x3F,0xFF,0xF9,0xE7,0x3F,
    0xFF,0xF9,0xE7,0x3F,0xFF,0xF9,0xC3,0x3F,0xFF,0xF9,0x81,0x3F,0xFF,0xF0,0x81,0x3F,
    0xFF,0xF0,0x81,0x3F,0xFF,0xF0,0x81,0x3F,0xFF,0xF9,0x81,0x3F,0xFF,0xF9,0xC3,0x3F,
    0xFF,0xF9,0xE7,0x3F,0xFF,0xF9,0xE7,0x3F,0xFF,0xF9,0xE7,0x3F,0xFF,0xFF,0xFF,0x3F,
    0xFF,0xFF,0xFF,0x3F,0xFF,0xFF,0xFF,0x3F
  },
  {
    0xFF,0xFF,0xFF,0x3F,0xFF,0xFF,0xFF,0x3F,0xEF,0xFF,0xFF,0x3F,0xC7,0xFF,0xFF,0x3F,
    0xC7,0xF3,0xFF,0x3F,0x83,0xC0,0xFF,0x3F,0xEF,0xCC,0xFF,0x3F,0x6F,0x9E,0xFF,0x3F,
    0x6F,0x9E,0xFF,0x3F,0x2F,0x3F,0xFF,0x3F,0x2F,0x3F,0xFF,0x3F,0x8F,0x7F,0xFE,0x3F,
    0x8F,0x7F,0xFE,0x39,0x8F,0x7F,0xFE,0x39,0xCF,0xFF,0xFC,0x3C,0xCF,0xFF,0xFC,0x3C,
    0xEF,0xFF,0xFC,0x3C,0xEF,0xFF,0x79,0x3E,0xEF,0xFF,0x79,0x3E,0xEF,0xFF,0x33,0x3F,
    0xEF,0xFF,0x33,0x3F,0xEF,0xFF,0x87,0x3F,0xEF,0xFF,0xCF,0x3F,0xEF,0xFF,0x7F,0x3E,
    0xEF,0xFF,0x7F,0x38,0x0F,0x00,0x00,0x30,0xFF,0xFF,0x7F,0x38,0xFF,0xFF,0x7F,0x3E,
    0xFF,0xFF,0xFF,0x3F,0xFF,0xFF,0xFF,0x3F,
  },
  {
    0xFF,0xFF,0xFF,0x3F,0xFF,0xFF,0xFF,0x3F,0xFF,0xFF,0xFF,0x3F,0xFF,0xFF,0xFF,0x3F,
    0xFF,0x1F,0xFE,0x3F,0xFF,0x1F,0xFE,0x3F,0xFF,0x0C,0xCC,0x3F,0x7F,0x00,0x80,0x3F,
    0x3F,0x00,0x00,0x3F,0x3F,0xE0,0x01,0x3F,0x7F,0xF8,0x87,0x3F,0x7F,0xFC,0x8F,0x3F,
    0x3F,0xFC,0x0F,0x3F,0x0F,0x3E,0x1F,0x3C,0x0F,0x1E,0x1E,0x3C,0x0F,0x1E,0x1E,0x3C,
    0x0F,0x3E,0x1F,0x3C,0x3F,0xFC,0x0F,0x3F,0x7F,0xFC,0x8F,0x3F,0x7F,0xF8,0x87,0x3F,
    0x3F,0xE0,0x01,0x3F,0x3F,0x00,0x00,0x3F,0x7F,0x00,0x80,0x3F,0xFF,0x0C,0xCC,0x3F,
    0xFF,0x1F,0xFE,0x3F,0xFF,0x1F,0xFE,0x3F,0xFF,0xFF,0xFF,0x3F,0xFF,0xFF,0xFF,0x3F,
    0xFF,0xFF,0xFF,0x3F,0xFF,0xFF,0xFF,0x3F
  },
};

/************************************* 页面变量 *************************************/

//OLED变量
#define   DISP_H              64    //屏幕高度
#define   DISP_W              128   //屏幕宽度
uint8_t   *buf_ptr;                 //指向屏幕缓冲的指针
uint16_t  buf_len;                  //缓冲长度

//UI变量
#define   UI_DEPTH            20    //最深层级数
#define   UI_MNUMB            100   //菜单数量
#define   UI_PARAM            16    //参数数量
enum 
{
  DISP_BRI,     //屏幕亮度
  TILE_ANI,     //磁贴动画速度
  LIST_ANI,     //列表动画速度
  WIN_ANI,      //弹窗动画速度
  SPOT_ANI,     //聚光动画速度
  TAG_ANI,      //标签动画速度
  FADE_ANI,     //消失动画速度
  BTN_SPT,      //按键短按时长
  BTN_LPT,      //按键长按时长
  TILE_UFD,     //磁贴图标从头展开开关
  LIST_UFD,     //菜单列表从头展开开关
  TILE_LOOP,    //磁贴图标循环模式开关
  LIST_LOOP,    //菜单列表循环模式开关
  WIN_BOK,      //弹窗背景虚化开关
  KNOB_DIR,     //旋钮方向切换开关
  DARK_MODE,    //黑暗模式开关
};
struct 
{
  bool      init;
  uint8_t   num[UI_MNUMB];
  uint8_t   select[UI_DEPTH];
  uint8_t   layer;
  uint8_t   index = M_SLEEP;
  uint8_t   state = S_NONE;
  bool      sleep = true;
  uint8_t   fade = 1;
  uint8_t   param[UI_PARAM];
} ui;

//磁贴变量
//所有磁贴页面都使用同一套参数
#define   TILE_B_FONT         u8g2_font_helvB18_tr        //磁贴大标题字体
#define   TILE_S_FONT         u8g2_font_HelvetiPixel_tr   //磁贴小标题字体
#define   TILE_B_TITLE_H      18                          //磁贴大标题字体高度
#define   TILE_ICON_H         30                          //磁贴图标高度
#define   TILE_ICON_W         30                          //磁贴图标宽度
#define   TILE_ICON_S         36                          //磁贴图标间距
#define   TILE_INDI_H         27                          //磁贴大标题指示器高度
#define   TILE_INDI_W         7                           //磁贴大标题指示器宽度
#define   TILE_INDI_S         36                          //磁贴大标题指示器上边距
struct 
{
  float   title_y_calc = TILE_INDI_S + (TILE_INDI_H - TILE_B_TITLE_H) / 2 + TILE_B_TITLE_H * 2;
  float   title_y_trg_calc = TILE_INDI_S + (TILE_INDI_H - TILE_B_TITLE_H) / 2 + TILE_B_TITLE_H;
  int16_t temp;
  bool    select_flag;
  float   icon_x;
  float   icon_x_trg;
  float   icon_y;
  float   icon_y_trg;
  float   indi_x; 
  float   indi_x_trg;
  float   title_y;
  float   title_y_trg;
} tile;

//列表变量

//默认参数
#define   LIST_FONT           u8g2_font_HelvetiPixel_tr   //列表字体
#define   LIST_TEXT_H         8                           //列表每行文字字体的高度
#define   LIST_LINE_H         16                          //列表单行高度
#define   LIST_TEXT_S         4                           //列表每行文字的上边距，左边距和右边距，下边距由它和字体高度和行高度决定
#define   LIST_BAR_W          5                           //列表进度条宽度，需要是奇数，因为正中间有1像素宽度的线
#define   LIST_BOX_R          0.5                         //列表选择框圆角

/*
//超窄行高度测试
#define   LIST_FONT           u8g2_font_4x6_tr            //列表字体
#define   LIST_TEXT_H         5                           //列表每行文字字体的高度
#define   LIST_LINE_H         7                           //列表单行高度
#define   LIST_TEXT_S         1                           //列表每行文字的上边距，左边距和右边距，下边距由它和字体高度和行高度决定
#define   LIST_BAR_W          7                           //列表进度条宽度，需要是奇数，因为正中间有1像素宽度的线
#define   LIST_BOX_R          0.5                         //列表选择框圆角
*/
struct
{
  uint8_t line_n = DISP_H / LIST_LINE_H;
  int16_t temp;
  bool    loop;
  float   y;
  float   y_trg;
  float   box_x;
  float   box_x_trg;
  float   box_y;
  float   box_y_trg[UI_DEPTH];
  float   bar_y;
  float   bar_y_trg;
} list;

//电压测量页面变量
//开发板模拟引脚
uint8_t   analog_pin[10] = { PA0, PA1, PA2, PA3, PA4, PA5, PA6, PA7, PB0, PB1 };
//曲线相关
#define   WAVE_SAMPLE         20                          //采集倍数
#define   WAVE_W              94                          //波形宽度
#define   WAVE_L              24                          //波形左边距
#define   WAVE_U              0                           //波形上边距
#define   WAVE_MAX            27                          //最大值
#define   WAVE_MIN            4                           //最小值
#define   WAVE_BOX_H          32                          //波形边框高度
#define   WAVE_BOX_W          94                          //波形边框宽度
#define   WAVE_BOX_L_S        24                          //波形边框左边距
//列表和文字背景框相关
#define   VOLT_FONT           u8g2_font_helvB18_tr        //电压数字字体
#define   VOLT_TEXT_BG_L_S    24                          //文字背景框左边距
#define   VOLT_TEXT_BG_W      94                          //文字背景框宽度
#define   VOLT_TEXT_BG_H      29                          //文字背景框高度
struct
{
  int     ch0_adc[WAVE_SAMPLE * WAVE_W];
  int     ch0_wave[WAVE_W];
  int     val;
  float   text_bg_r; 
  float   text_bg_r_trg; 
} volt;

//选择框变量

//默认参数
#define   CHECK_BOX_L_S       95                          //选择框在每行的左边距
#define   CHECK_BOX_U_S       2                           //选择框在每行的上边距
#define   CHECK_BOX_F_W       12                          //选择框外框宽度
#define   CHECK_BOX_F_H       12                          //选择框外框高度
#define   CHECK_BOX_D_S       2                           //选择框里面的点距离外框的边距

/*
//超窄行高度测试
#define   CHECK_BOX_L_S       99                          //选择框在每行的左边距
#define   CHECK_BOX_U_S       0                           //选择框在每行的上边距
#define   CHECK_BOX_F_W       5                           //选择框外框宽度
#define   CHECK_BOX_F_H       5                           //选择框外框高度
#define   CHECK_BOX_D_S       1                           //选择框里面的点距离外框的边距
*/
struct
{
  uint8_t *v;
  uint8_t *m;
  uint8_t *s;
  uint8_t *s_p;
} check_box;

//弹窗变量
#define   WIN_FONT            u8g2_font_HelvetiPixel_tr   //弹窗字体
#define   WIN_H               32                          //弹窗高度
#define   WIN_W               102                         //弹窗宽度
#define   WIN_BAR_W           92                          //弹窗进度条宽度
#define   WIN_BAR_H           7                           //弹窗进度条高度
#define   WIN_Y               - WIN_H - 2                 //弹窗竖直方向出场起始位置
#define   WIN_Y_TRG           - WIN_H - 2                 //弹窗竖直方向退场终止位置
struct
{
  //uint8_t
  uint8_t   *value;
  uint8_t   max;
  uint8_t   min;
  uint8_t   step;

  MENU      *bg;
  uint8_t   index;
  char      title[20];
  uint8_t   select;
  uint8_t   l = (DISP_W - WIN_W) / 2;
  uint8_t   u = (DISP_H - WIN_H) / 2;
  float     bar;
  float     bar_trg;
  float     y;
  float     y_trg;
} win;

//聚光灯变量
struct
{
  float   l; 
  float   l_trg; 
  float   r; 
  float   r_trg; 
  float   u; 
  float   u_trg; 
  float   d; 
  float   d_trg; 
} spot;

/************************************* USB 相关 *************************************/

#include <USBComposite.h>

USBHID HID;

const uint8_t reportDescription[] = 
{
   HID_CONSUMER_REPORT_DESCRIPTOR(),
   HID_KEYBOARD_REPORT_DESCRIPTOR()
};

HIDConsumer Consumer(HID);
HIDKeyboard Keyboard(HID);

void hid_init()
{
  HID.begin(reportDescription, sizeof(reportDescription));
  while (!USBComposite);
}

/********************************** 自定义功能变量 **********************************/

/********************************** 旋钮 HID 控制 **********************************/

//旋钮功能变量
#define   KNOB_PARAM          4
#define   KNOB_ROT_DIS        0
#define   KNOB_ROT_VOL        1
#define   KNOB_ROT_BRI        2
enum 
{
  KNOB_ROT,       //睡眠下旋转旋钮的功能，0 禁用，1 音量，2 亮度
  KNOB_COD,       //睡眠下短按旋钮输入的字符码，0 禁用
  KNOB_ROT_P,     //旋转旋钮功能在单选框中选择的位置
  KNOB_COD_P,     //字符码在单选框中选择的位置
};
struct 
{
  uint8_t param[KNOB_PARAM] = { 0, 0, 2, 2 }; //禁用在列表的第2个选项，第0个是标题，第1个是分界线
} knob;

/********************************** Rapid Trigger **********************************/

// 按键参数
#define         KEYS        10
#define         LIGHT       PC13
#define         KEY_DIS     0
#define         KEY_MODE1   1
#define         KEY_MODE2   2
enum 
{
  K0,
  K1,
  K2,
  K3,
  K4,
  K5,
  K6,
  K7,
  K8,
  K9,
};
enum 
{
  TRIGGER,
  RELEASE,
  TOP, 
  BOTTOM,
  TIMES,
  CODES,
  MODES,
  CODES_P,
  MODES_P,
  PINS,
  TRAVEL,
};

// 按键变量
uint8_t key [KEYS][11] =
{ 
//  trigger  release   top   bottom   times   codes     modes    codes_p  modes_p   pins  travel
  {    3,       3,      3,     3,      10,   KEY_DIS, KEY_MODE1,    2,      2,      PA0,    40 },  // K0
  {    3,       3,      3,     3,      10,   KEY_DIS, KEY_MODE1,    2,      2,      PA1,    40 },  // K1
  {    3,       3,      3,     3,      10,   KEY_DIS, KEY_MODE1,    2,      2,      PA2,    40 },  // K2
  {    3,       3,      3,     3,      10,   KEY_DIS, KEY_MODE1,    2,      2,      PA3,    40 },  // K3
  {    3,       3,      3,     3,      10,   KEY_DIS, KEY_MODE1,    2,      2,      PA4,    40 },  // K4
  {    3,       3,      3,     3,      10,   KEY_DIS, KEY_MODE1,    2,      2,      PA5,    40 },  // K5
  {    3,       3,      3,     3,      10,   KEY_DIS, KEY_MODE1,    2,      2,      PA6,    40 },  // K6
  {    3,       3,      3,     3,      10,   KEY_DIS, KEY_MODE1,    2,      2,      PA7,    40 },  // K7
  {    3,       3,      3,     3,      10,   KEY_DIS, KEY_MODE1,    2,      2,      PB0,    40 },  // K8
  {    3,       3,      3,     3,      10,   KEY_DIS, KEY_MODE1,    2,      2,      PB1,    40 },  // K9
};

/************************************* 按键扫描 *************************************/

// 按键参数结构体
struct 
{
  int   min;
  int   max;
  int   trigger;
  int   release;
  int   value;
  int   reference;
  int   unit;
  int   cushion;
  bool  init;  
  bool  pressed;
} keyx[KEYS];

/************************************* 不分模式 *************************************/

// 初始化
void key_init() 
{
  // 打开初始化指示灯
  pinMode(LIGHT, OUTPUT);
  digitalWrite(LIGHT, LOW);

  // 读模拟量，最大值和最小值先暂定为当前值
  for (uint8_t n = 0; n < KEYS; ++n) 
  {
    pinMode(key[n][PINS],INPUT_ANALOG);
    keyx[n].value = analogRead(key[n][PINS]);
    keyx[n].min = keyx[n].value;
    keyx[n].max = keyx[n].value;
  }

  // 并行扫描所有传感器，记录每个传感器的初始抖动范围，每1ms扫描一次，扫描1s
  for (int i = 0; i < 1000; ++i) 
  {
    for (uint8_t n = 0; n < KEYS; ++n) 
    {
      keyx[n].value = analogRead(key[n][PINS]);
      if (keyx[n].value < keyx[n].min) 
      {
        keyx[n].min = keyx[n].value;
      } 
      else if (keyx[n].value > keyx[n].max) 
      {
        keyx[n].max = keyx[n].value;
      }    
    }
    delay(1);
  }

  for (uint8_t n = 0; n < KEYS; ++n) 
  {
    keyx[n].cushion = (keyx[n].max - keyx[n].min) * key[n][TIMES];      // 计算缓冲值

    // 初始化一些参数
    keyx[n].init = false;                                               // 按键还没有被首次按下
    keyx[n].reference = keyx[n].value;                                  // 初始化参考值为当前值
    keyx[n].trigger = key[n][TRIGGER] * keyx[n].cushion;                // 初始化触发值，避免插上的瞬间有输入
    keyx[n].release = key[n][RELEASE] * keyx[n].cushion;                // 初始化释放值，避免插上的瞬间有输入

    if (key[n][MODES] == 1)
    {
      keyx[n].min = keyx[n].value;                                      // 初始化最小值，暂定为当前值
      keyx[n].max = keyx[n].value + keyx[n].cushion;                    // 初始化最大值，暂定为当前值 + 缓冲值
    }
    else if (key[n][MODES] == 2)
    {
      keyx[n].min = keyx[n].value - keyx[n].cushion;                    // 初始化最小值，暂定为当前值
      keyx[n].max = keyx[n].value;                                      // 初始化最大值，暂定为当前值 + 缓冲值
    }
  }

  // 关闭初始化指示灯
  digitalWrite(LIGHT, HIGH);
}

// 转换距离，将以毫米为单位的值转换成模拟量，假设磁铁外磁场强度均匀变化，则距离与模拟量线性相关
void convertDistance(uint8_t n) 
{
  keyx[n].unit = (keyx[n].max - keyx[n].min) / key[n][TRAVEL];
  keyx[n].trigger = keyx[n].unit * key[n][TRIGGER];
  keyx[n].release = keyx[n].unit * key[n][RELEASE];
}

/************************************* 区分模式 *************************************/

/*************************************  模式 1  *************************************/

// 按下按键，发送后改变按键状态，按键首次被按下
void pressKey_1(uint8_t n) 
{
  if (keyx[n].init)
  {
    Keyboard.press(key[n][CODES]);
  } 
  else if (keyx[n].value > keyx[n].min + keyx[n].cushion)
  {
    keyx[n].init = true;
  }
  keyx[n].pressed = true;
}

// 释放按键，发送后改变按键状态，按键首次被按下
void releaseKey_1(uint8_t n) 
{
  if (keyx[n].init)
  {
    Keyboard.release(key[n][CODES]);
  } 
  else if (keyx[n].value > keyx[n].min + keyx[n].cushion)
  {
    keyx[n].init = true;
  }
  keyx[n].pressed = false;
}

// 平衡按键，按下时探索更大的值，释放时探索更小的值，以免在使用时极值漂移使抖动能误触发
void balanceKey_1(uint8_t n) 
{
  if (!keyx[n].pressed && (keyx[n].value < keyx[n].min)) 
  {
    keyx[n].min = keyx[n].value;
    convertDistance(n);
  } 
  else if (keyx[n].pressed && (keyx[n].value > keyx[n].max)) 
  {
    keyx[n].max = keyx[n].value;
    convertDistance(n);
  }
}
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
void loop() 
{
  btn_scan();
  ui_proc();
}

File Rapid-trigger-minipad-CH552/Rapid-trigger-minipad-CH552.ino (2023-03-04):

/*
  此程序用于实现wooting键盘中的Rapid trigger功能，移植并优化自Github上的一个开源项目，添加了按键的独立参数，优化了确定缓冲值的方式。

  为提高易读性，此程序并未严格遵守编写规范，请在开头处“需要自定义的参数”中更改和添加相关量以适应手感和实现功能，若不想了解运行原理，则不必理会下面所有的参数和函数。

  测试用开发板为CH552G，注意，当它用作USB设备时，每次上传程序都需要按住板子上的按钮同时插入电脑，再松开按钮，电脑才能识别到。
  
  上传程序前请确认以下设置是正确的：

    文件 -> 首选项 -> 其他开发板管理器地址 -> 添加一行：https://github.com/DeqingSun/ch55xduino
    工具 -> 开发板 -> 搜索ch552，安装以CH55xduino开头的环境
    工具 -> 开发板 -> CH55xduino...  -> CH552 Board
    工具 -> Clock Source -> 24MHz(Internal),5V;
    工具 -> Upload method -> USB
    工具 -> USB Settings -> USER CODE w/148B USB RAM

    设置参考：https://github.com/DeqingSun/ch55xduino ； 

    原始项目：https://github.com/chent7/hall-2k-keypad-handmade

  本项目使用Apache 2.0开源协议，如需商用或借鉴，请阅读此协议。
  
  欢迎关注我的B站账号，一个只分享osu!相关内容，很无聊的帐号。
  
  用户名：音游玩的人，B站主页：https://space.bilibili.com/9182439?spm_id_from=..0.0
*/

/******************** 需要自定义的参数 ********************/

#define     KEYS  1                      // 按键数，下面的参数表是故意对齐的，每一列对应一个按键
const int   keyPins[KEYS]    = {  11 };  // 引脚号，只能使用有ADC功能的引脚，详情看引脚图
const char  keyCodes[KEYS]   = { 'z' };  // 按键值，注意要用单引号括住键值
const float trigger_mm[KEYS] = { 0.9 };  // 触发值，向下移动多远能触发，单位mm
const float release_mm[KEYS] = { 0.8 };  // 释放值，向上移动多远能释放，单位mm
const int   travel[KEYS]     = {   4 };  // 总行程，轴体本身的物理参数，单位mm

/***************** 不需要修改的参数和函数 *****************/

// 头文件和USB设置
#ifndef USER_USB_RAM
#error "This example needs to be compiled with a USER USB setting"
#endif
#include "src/userUsbHidKeyboardMouse/USBHIDKeyboardMouse.h"

// 按键参数结构体
struct {
  int min;
  int max;
  int trigger;
  int release;
  int value;
  int reference;
  bool pressed;
} keys[KEYS];

// 按下按键，发送后改变按键状态
void pressKey(int n) {
  Keyboard_press(keyCodes[n]);
  keys[n].pressed = true;
}

// 释放按键，发送后改变按键状态
void releaseKey(int n) {
  Keyboard_release(keyCodes[n]);
  keys[n].pressed = false;
}

// 转换距离，将以毫米为单位的值转换成模拟量，假设磁铁外磁场强度均匀变化，则距离与模拟量线性相关
void convertDistance(int n) {
  keys[n].trigger = ((keys[n].max - keys[n].min) / travel[n]) * trigger_mm[n];
  keys[n].release = ((keys[n].max - keys[n].min) / travel[n]) * release_mm[n];
}

// 按键初始化
void initKey(int n) {
  
  // 读模拟量，最大值和最小值先暂定为当前值
  pinMode(keyPins[n],INPUT);
  keys[n].value = analogRead(keyPins[n]);
  keys[n].min = keys[n].value;
  keys[n].max = keys[n].value;

  // 给每个按键1s的时间，记录抖动范围，此时应保证按键不受力
  for (int i = 0; i < 1000; i++) {
    keys[n].value = analogRead(keyPins[n]);
    if (keys[n].value < keys[n].min) {
      keys[n].min = keys[n].value;
    } else if (keys[n].value > keys[n].max) {
      keys[n].max = keys[n].value;
    }
    delay(1);
  }

  // 计算缓冲值，为抖动范围的10倍，如果插上后一直有输入，需要按一下按键才停止，尝试增大这个值
  int cushion = (keys[n].max - keys[n].min) * 30;

  // 设置最值，最小值不应该减去缓冲值，以避免扩大模拟量的范围
  keys[n].min = keys[n].value;
  keys[n].max = keys[n].value + cushion;

  // 初始化触发值和释放值，避免插上的瞬间有输入
  keys[n].trigger = trigger_mm[n] * cushion;
  keys[n].release = release_mm[n] * cushion;

  // 初始化参考值
  keys[n].reference = keys[n].value;
}

// 平衡按键，按下时探索更大的值，释放时探索更小的值，完整按下一次后能精确记录模拟量范围
void balanceKey(int n) {
  if (!keys[n].pressed && (keys[n].value < keys[n].min)) {
    keys[n].min = keys[n].value;
    convertDistance(n);
  } else if (keys[n].pressed && (keys[n].value > keys[n].max)) {
    keys[n].max = keys[n].value;
    convertDistance(n);
  }
}

// 按键移动时判断状态，同时动态改变参考值
void processKey(int n) {
  if (!keys[n].pressed) {
    if (keys[n].value > keys[n].reference + keys[n].trigger) {
      pressKey(n);
    }

    if (keys[n].value < keys[n].reference) {
      keys[n].reference = keys[n].value;
    }
  } else {
    if (keys[n].value <= keys[n].reference - keys[n].release) {
      releaseKey(n);
    }

    if (keys[n].value > keys[n].reference) {
      keys[n].reference = keys[n].value;
    }
  }
}

// 扫描一次按键
void runKey(int n) {
  keys[n].value = analogRead(keyPins[n]);
  balanceKey(n);
  processKey(n);
}

// 初始化
void setup() {
  for (int i = 0; i < KEYS; i++) {
    initKey(i);
  }
  USBInit();
}

// 循环体
void loop() {
  for (int i = 0; i < KEYS; i++) {
    runKey(i);
  }
}

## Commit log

2023-01-20 v 1.0
    用于单个按键的验证程序
2023-02-03 v 2.0
    看注释
2023-02-22 v 1.1
    出于性能和性价比的考虑，这两种开发板没有必要更新了，但还是保留在这给有需要的人，请参考STM32最新版本进行修改。
2023-02-24 v 1.1
    增加了十按键版本和填充模块
2023-03-04 add hardware "Ops03" PCB for test
2023-03-04 v 1.1
    [1. 磁铁固定器，1件.stl, 1. 触盘外壳A，1件.stl, 2. 探头固定器A，1件.stl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]
2023-03-04 跟着教程制作的，只需要下载这个包，上面的算是预览
    软件版本：v 1.2
    硬件版本：v 1.1
2023-03-05 跟着教程制作的，只需要下载这个包，上面的算是预览
    软件版本：v 1.3
    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
2023-03-10 增加一个推荐项目：BexPad
2023-03-31 v 2.0
    增加控制器，详情看项目主页末尾的更新说明
2023-03-31 增加控制器说明和演示视频
2023-05-09 Update README.md
    软件 v 3.0
2023-05-26 增加一个设计
2023-05-28 跟着教程制作的，只需要下载这个包，上面的算是预览
    修正部分描述问题
